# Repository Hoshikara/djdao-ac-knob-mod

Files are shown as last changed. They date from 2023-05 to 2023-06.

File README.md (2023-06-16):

# PURPOSE
To bring the feel of DJ DAO's arcade knobs closer to Valkyrie Model knobs. This is done by replacing the original plastic bushings with ball bearings. As some of the original parts cannot fit these ball bearings, they are replaced with custom parts. The ball bearings are more durable, provide a much smoother turning feel, and are easier to replace (if ever needed) than the proprietary plastic bushings.

# IMPORTANT
- This mod is **not** intended for NEMSYS cabinet knobs as the mounting holes are not the same.
- This mod utilizes the online laser cutting service [SendCutSend](https://sendcutsend.com/) which only ships to the US and Canada. If you live outside of these countries, you will need to find an alternative service to produce the parts.
- This mod is slightly destructive as the shaft of the knob assemblies require sanding to fit through one of the bearings.
- The custom top plate has oversized slots for the torque limiter tabs. This is arcade accurate as opposed to the exact fit of the original top plate slots.
- The approximate cost of materials is $70 USD at the time of writing (June 2023).
- If you have access to a 3D printer, consider [this](https://github.com/arkeet/svre9-knob-mod) modifcation instead.

# TOOLS AND MATERIALS
- 2x [Custom Top Plate](./top_plate/)
- 2x [Custom U Bracket](./u_bracket/)
- 2x MISUMI Resin Washers WSJW10-6-2, available at [YubiParts](https://yubiparts.com/products/misumi-wsjw10-6-2-resin-washers-2x-for-sound-voltex-sdvx?variant=41889513636027) or [bluespringexpress](https://bluespringexpress.net/en-us/products/sound-voltex-misumi-resin-washers-wsjw10-6-2)
- Find these on Amazon, AliExpress, etc.:
    - 2x MF106ZZ Flanged Ball Bearing 6x10x3mm
    - 2x MF148ZZ Flanged Ball Bearing 8x14x4mm
    - 200-400 grit sandpaper
    - 7mm socket wrench screwdriver
    - 1.5mm and 2mm hex key allen wrenches

# ASSEMBLY

Knob Assembly Exploded View

## Parts of interest:
- `1` is the U bracket, replace it with the custom U bracket.
- `2` is the bottom plastic bushing, replace it with a MF148ZZ ball bearing. The hole in the U bracket may require sanding to fit the bearing, but try press fitting the bearing first.
- `3` is the shaft of the assembly. This part will likely require sanding, do so **only enough** to fit through the MF106ZZ bearing.
- `8` is the top plate, replace it with the custom top plate.
- `9` is the top plastic bushing, replace it with a MF106ZZ ball bearing.
- `10` is a MISUMI WSJW10-6-2 Resin Washer, not completely necessary but recommended to space the knob from the top plate.
- `B` is a 7mm hex nut, use the 7mm socket wrench screwdriver to remove these.
- `C` is a knob set screw, use the 2mm hex key allen wrench to remove these.
- `D` is the shaft set screw, use the 1.5mm hex key allen wrench to remove these.

## Disassembly and reassembly video:
SDVX AC-Style Knob Disassembly and Reassembly (https://www.youtube.com/watch?v=QxZ3BoAf3iQ)

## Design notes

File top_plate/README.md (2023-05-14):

# INSTRUCTIONS

1. Download the raw `top_plate.dxf` file.
   
2. Upload the file to [SendCutSend](https://app.sendcutsend.com/customer#/quote)
   
3. Verify that units are in `mm`
   
4. For material selection: `METALS -> ALUMINUM -> 5052 ALUMINUM -> .125" (3.2 MM)`
   
5. Choose to add hole operations to the design

6. For the middle holes on the left and right side:
   1. Select `Hardware` as the operation
   2. Click `OPEN CATALOG`
   3. Select `STUD`
   4. Select `FLUSH STUD, M4 X 0.7, .393"`
   
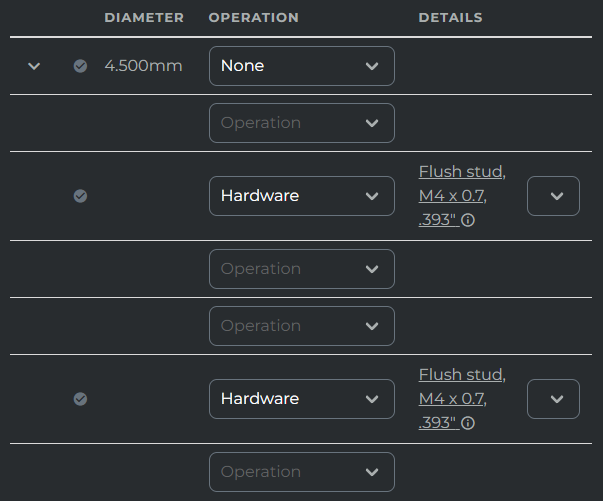
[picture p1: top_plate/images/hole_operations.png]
Hole Operations
   

7. Verify that the 3D model preview looks correct

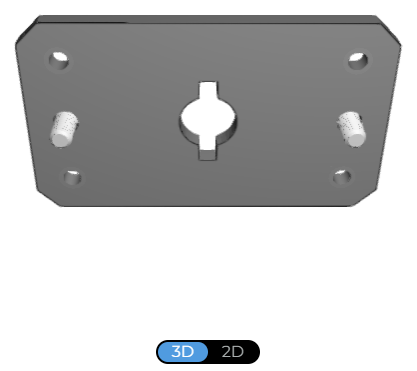
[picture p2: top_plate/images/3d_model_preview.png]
3D Model Preview


8. Change the quantity to `2` and add to cart

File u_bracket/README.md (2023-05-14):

# INSTRUCTIONS

1. Download the raw `u_bracket.dxf` file.
   
2. Upload the file to [SendCutSend](https://app.sendcutsend.com/customer#/quote)
   
3. Verify that units are in `mm`
   
4. For material selection: `METALS -> ALUMINUM -> 5052 ALUMINUM -> .040" (1.0 MM)`
   
5. Choose to add bending to the design and copy the following bend settings

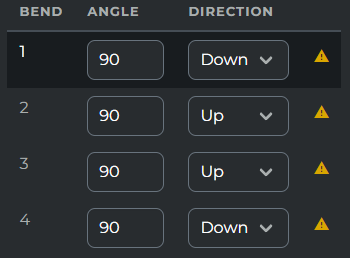
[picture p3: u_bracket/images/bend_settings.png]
Bend Settings


6. Verify that the 3D model preview looks correct

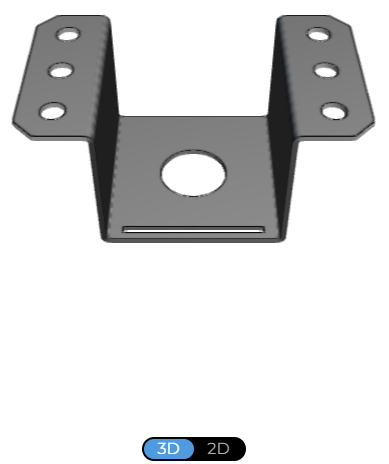
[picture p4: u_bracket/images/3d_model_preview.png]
3D Model Preview


7. Change the quantity to `2` and add to cart

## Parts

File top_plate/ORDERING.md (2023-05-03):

## INSTRUCTIONS

1. Download the `top_plate.dxf` file (right click and select `Save Link As`)
   
2. Upload the file to [SendCutSend](https://app.sendcutsend.com/customer#/quote)
   
3. Verify that units are in `mm`
   
4. For material selection:
   1. Select `METALS`
   2. Select `ALUMINUM`
   3. Select `5052 ALUMINUM`
   4. Select `.125" (3.2 MM)`
   
5. Choose to add hole operations to the design

6. For the middle holes on the left and right side:
   1. Select `Hardware` as the operation
   2. Click `OPEN CATALOG`
   3. Select `STUD`
   4. Select `FLUSH STUD, M4 X 0.7, .393"`
   
   Hole Operations

7. Verify that the 3D model preview looks correct 3D Model Preview

8. Change the quantity to `2` and add to cart

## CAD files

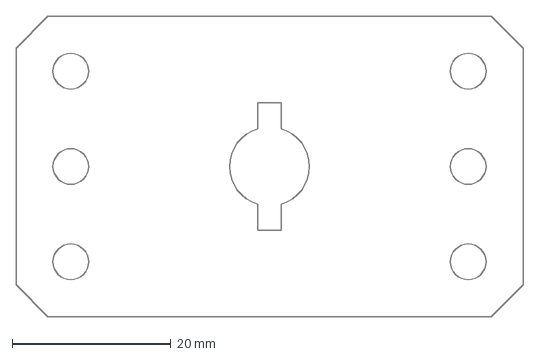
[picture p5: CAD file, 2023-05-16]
top_plate/top_plate.dxf
63.8 x 37.8 mm

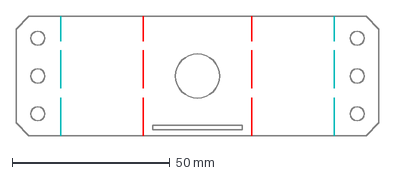
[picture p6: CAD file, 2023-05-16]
u_bracket/u_bracket.dxf
115.1 x 37.8 mm

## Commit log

2023-05-03 add ordering instructions
    [top_plate.dxf, u_bracket.dxf]
2023-05-03 update top plate instructions
2023-05-03 add tools and materials
2023-05-05 fix u bracket internal height
    [u_bracket.dxf]
2023-05-16 update dxf
    [top_plate.dxf, u_bracket.dxf]
2023-05-16 update top plate images
2023-05-16 update u bracket images
